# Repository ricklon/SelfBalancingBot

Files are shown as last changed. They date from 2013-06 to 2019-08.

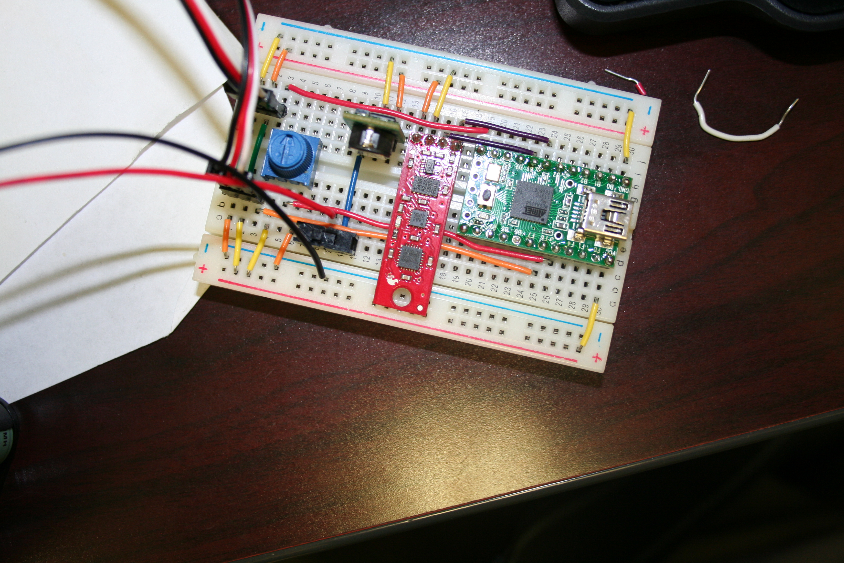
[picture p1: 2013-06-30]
docs/IMG_3596.JPG

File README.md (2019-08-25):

Self Balancing RoBot (SBR)
================
For more project information check out the [wiki](https://github.com/ricklon/SelfBalancingBot/wiki)

- [ ] Need to upgrade to faster motors
- [ ] Keep the servo style control
- [ ] May have to Create a a custom servo library
- [ ] Test with hobby gearnotor
- [ ] PID needs to coordinate 2 motors
- [ ] Would like to add support for mpu6500 and mpu9250
- [ ] Add multiple core support [Teensy 3.x, Fubarino Mini 2.0, esp32, esp8266]
- [ ] Motor controller l293d
- [ ] Evaluate power supply

This Self Balancing Robot project is for the Rutgers University  Governor School Course "How to Make a Self Balancing Robot" started by Aatish in 2012. He had the self balancing robot using the Sparkfun box. In addition Jason Doreweller, http://www.jddorweiler.appspot.com/electronics.html#robot,  created a Self Balancing Robot at Fubar Labs in 2012. Concepts from that robot where tested, and modeled developing this new robot.

This project has added:
* servo calibration sketches
* data gathering sketches and test for the accelermeter
* data gathering sketches and test for the gyro
* A servo movement library
* PID, Kalman fileter library

Arduino libraries used in the project:
* Servo
* ITG3200
* ADXL445
* Serial

BOM:
* Teensy 2.0
* 2 Parallax Continuous Servos
* 5v Switching voltage regulator
* Sparkfun 9 DOF freedom IMO

Note: Using the Teensy eliminated the Serial vs Servo timer problem.

Laser cut reference design for a body to mount the project.

Notes for Teensy 2.0
====
[I2C pin out]( http://www.pjrc.com/teensy/pinout2b.png)

[Teensy 2.0 pin mapping](http://www.pjrc.com/teensy/pinout.html)

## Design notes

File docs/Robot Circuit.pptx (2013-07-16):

## Robot Circuit

## Wiring

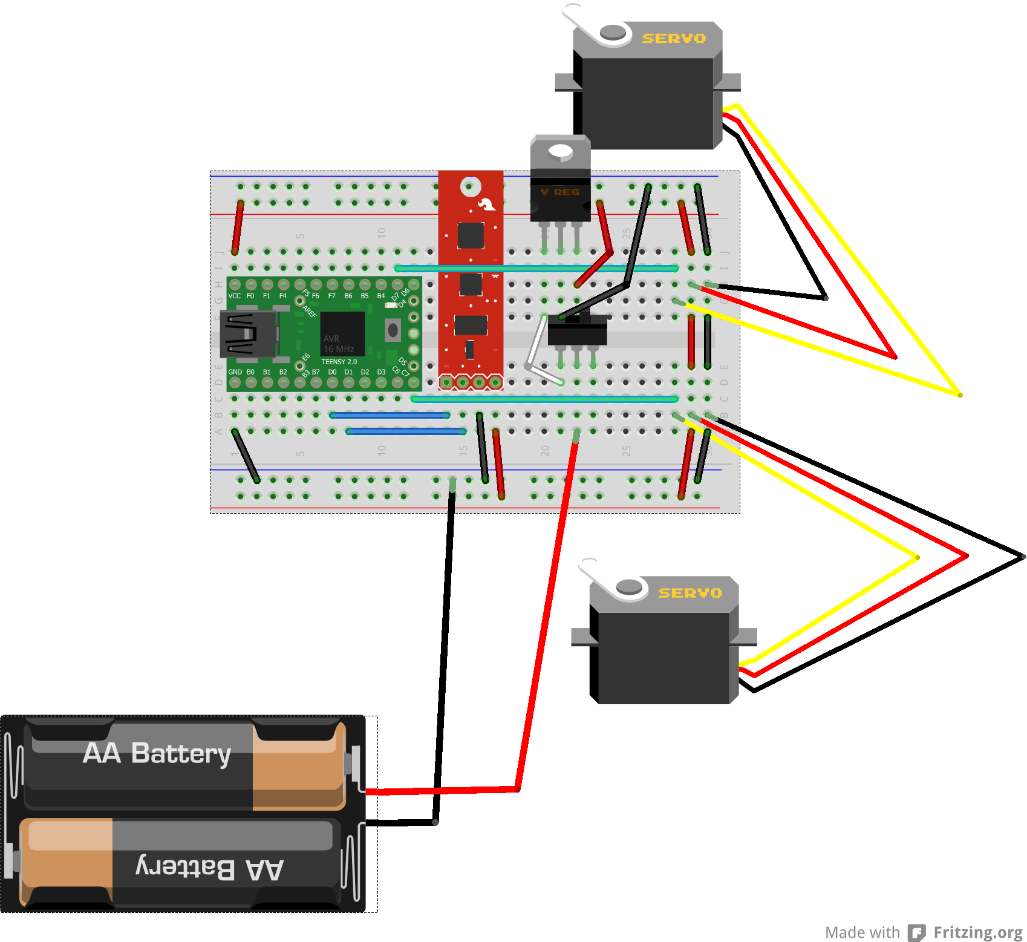
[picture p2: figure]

## Schematic

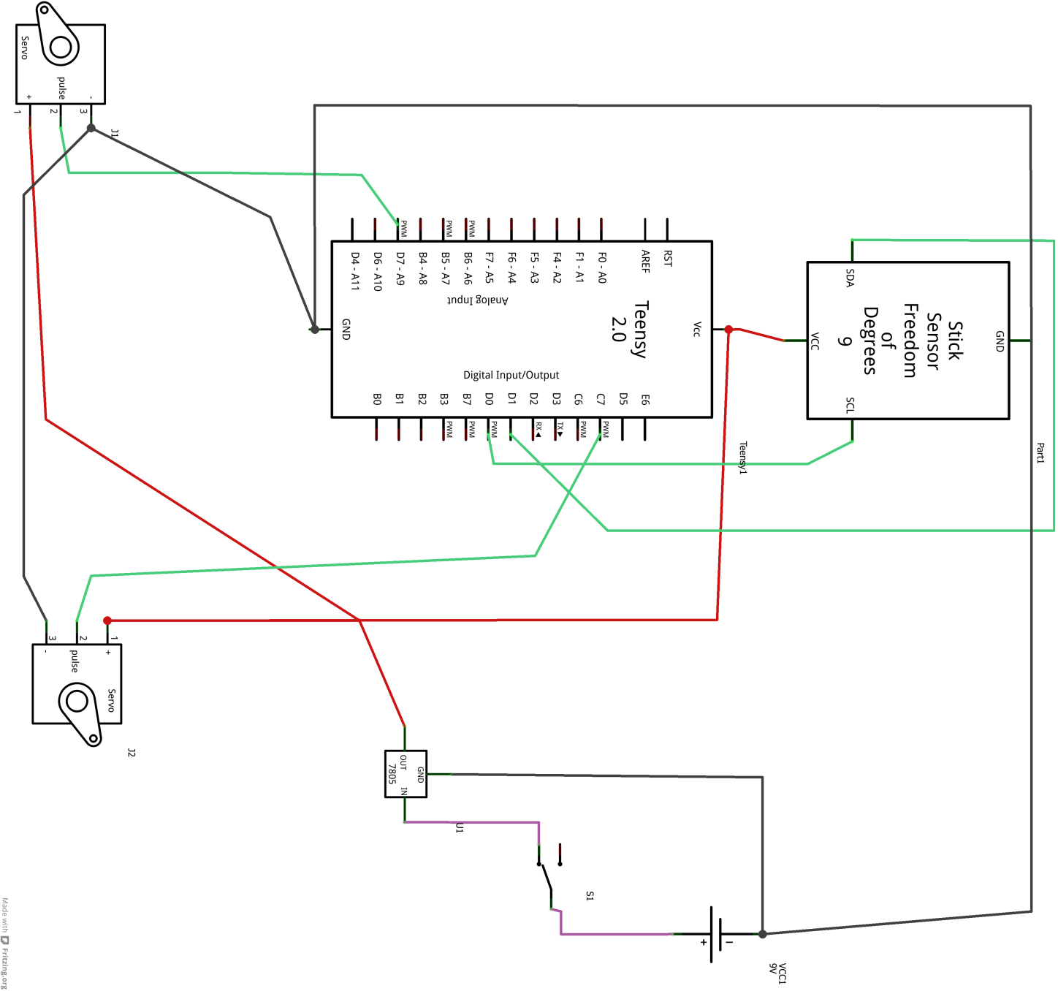
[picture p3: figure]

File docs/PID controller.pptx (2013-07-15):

## PID controller

## What’s a PID controller?

- A PID is defined by the following Equation
- Think of the Integral term as the “past”
- Think of the e(t) (proportional) term as “Now”
- Think of the Derivative term as the “Future”
- The constants reflect how important we think each of the other components are.

## In code: Setup

void setup()
{
…
for (int i = 0; i < REF_ANGLE_SAMPLES; i++){
getAccAngle();
getGyroValues();
maxGyro = absMax(gy,absMax(gx,gz));
maxAngle = absMax(theta,psi);
angle = compositeFilter( maxAngle, float(maxGyro), SAMPLE_RATE, angle);
refAngle += angle; delay(SAMPLE_RATE);
}
refAngle /= REF_ANGLE_SAMPLES;
…
}

## In code: Loop

void loop()
{
…
angle = compositeFilter( maxAngle, float(maxGyro), rate, angle);
float error = angle - refAngle;
integral = integral + error * rate;
derivative = (error - prevError) / rate;
spd = (KP * error) + (KI * integral) + (KD * derivative);
prevError = error;
…
}

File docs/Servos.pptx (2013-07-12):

## Servos

## Controlling Rotation

Continuous Servo | Standard Servo | Stepper | Direct Motor
Pros: PWM speed control | Pros: PWM angle control | Pros: Precise angle control and Continuous rotation | Pros: Fast
Cons: No fine angle control | Cons: Upper limit on Turning | Cons: SLOWEST | Cons: No precision speed control (ON or OFF)

- It is possible to directly connect a motor to the arduino. I DO NOT recommend doing this. http:// (http://www.instructables.com/id/Simple-2-way-motor-control-for-the-arduino/?ALLSTEPS)www.instructables.com (http://www.instructables.com/id/Simple-2-way-motor-control-for-the-arduino/?ALLSTEPS)/id/Simple-2-way-motor-control-for-the- (http://www.instructables.com/id/Simple-2-way-motor-control-for-the-arduino/?ALLSTEPS)arduino (http://www.instructables.com/id/Simple-2-way-motor-control-for-the-arduino/?ALLSTEPS)/? (http://www.instructables.com/id/Simple-2-way-motor-control-for-the-arduino/?ALLSTEPS)ALLSTEPS (http://www.instructables.com/id/Simple-2-way-motor-control-for-the-arduino/?ALLSTEPS)
- We’re taking the Continuous Servo as the best compromise.

## Servo Wiring

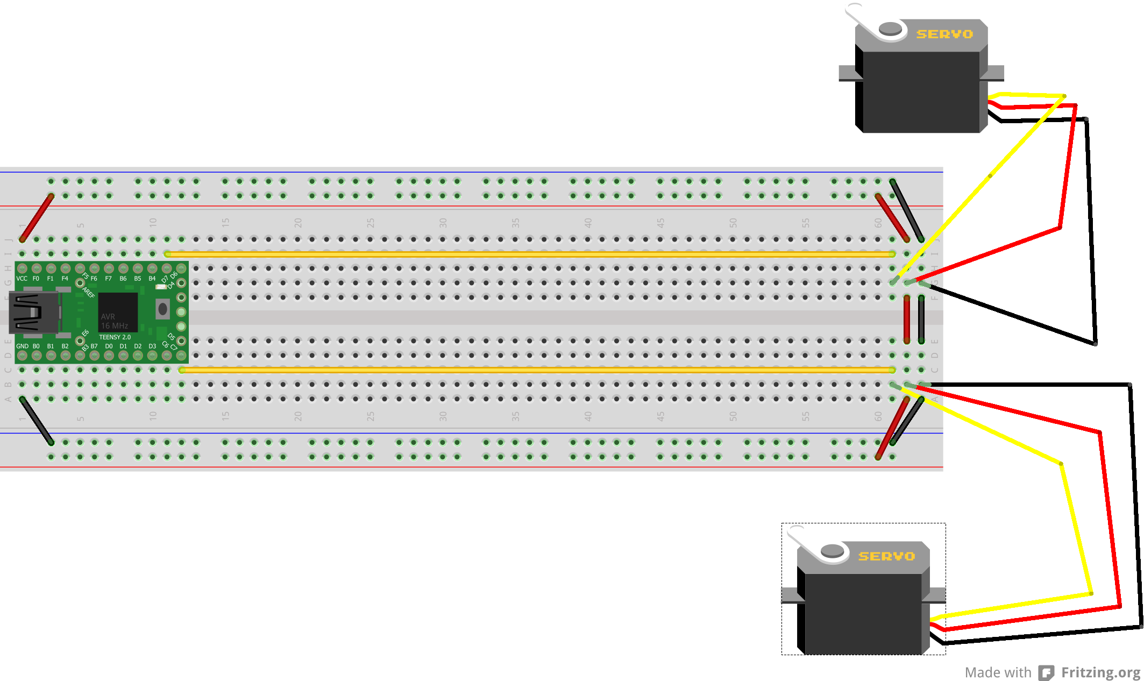
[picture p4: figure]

## Servo Circuit

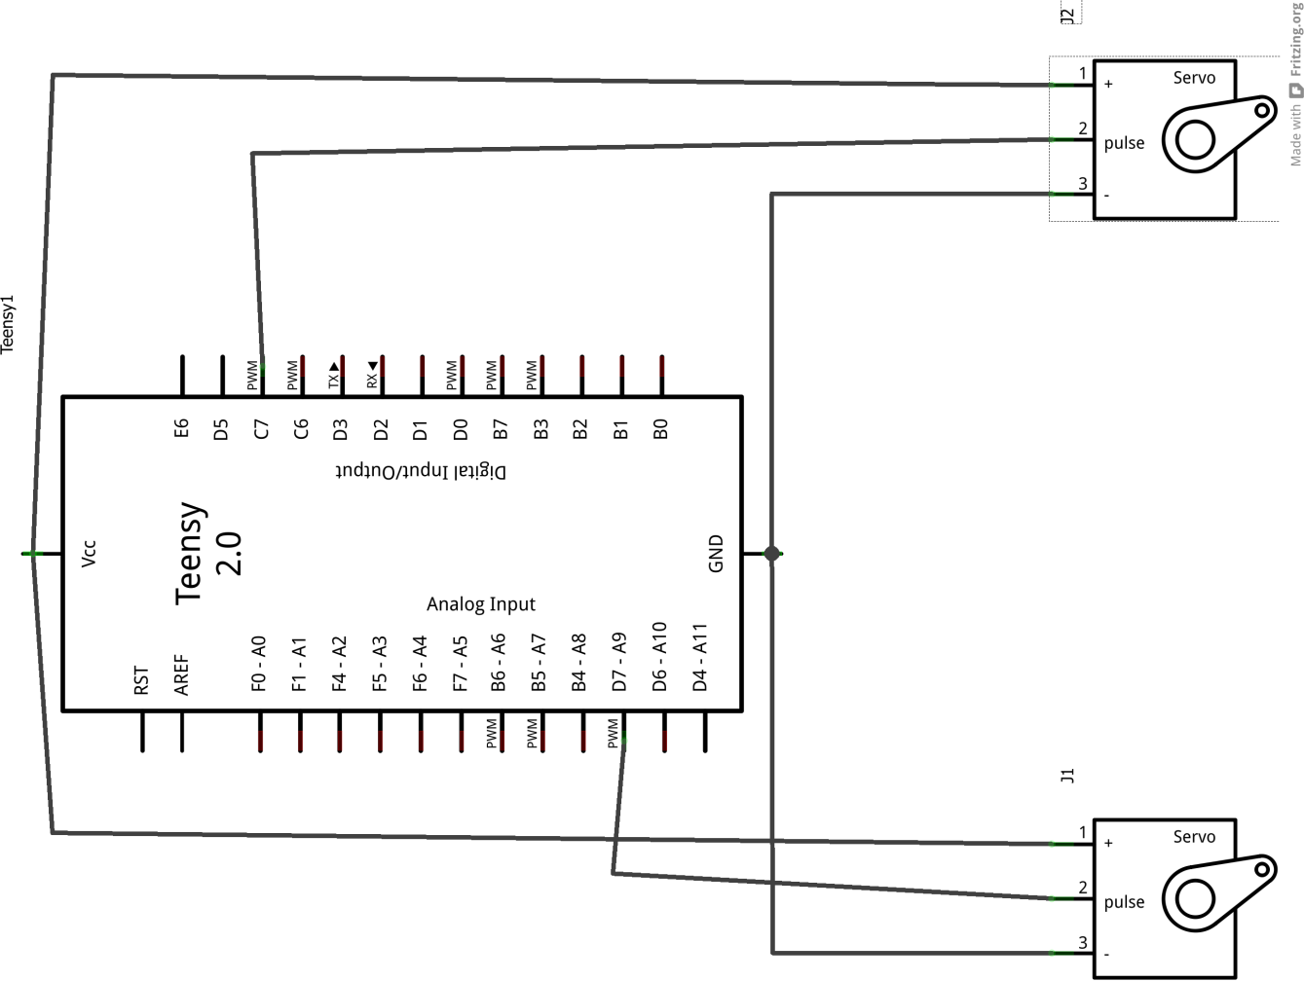
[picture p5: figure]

## PWM

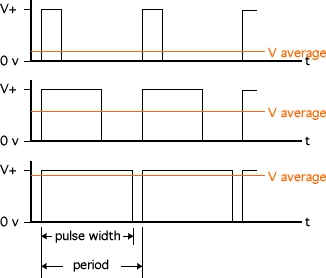
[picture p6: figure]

## Units

- Accelerometer function outputs angles in degrees
- Gyro outputs angle rates in degrees/sec
- Servo in controlled by Pulses in units of Microseconds?
- Servo max speed is in RPM? How do we convert?
- 1(Degrees)/(Seconds)=(Degrees)/(Seconds)∗(60 Seconds)/(Minute)∗(rotation)/(360 degrees)=1/6(rotation)/(minute)
- Need a conversion function from pulse widths to rotation speeds in (…)?

## Controlling the Servo

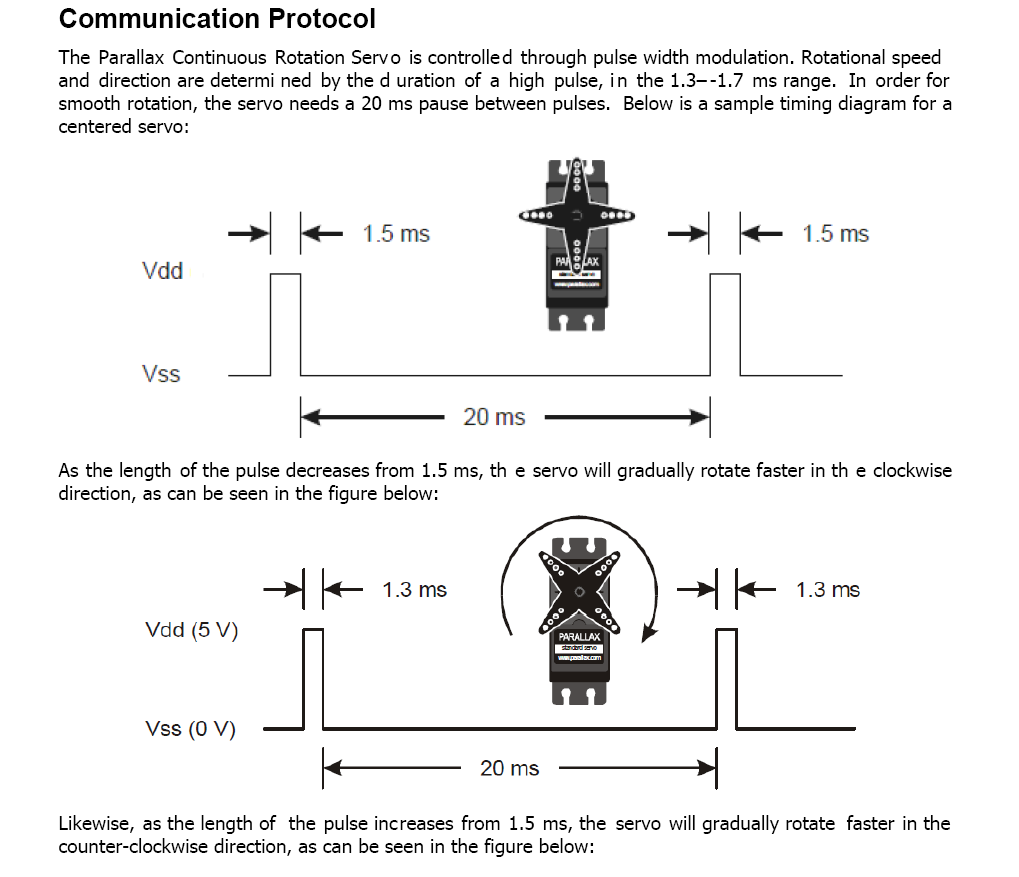
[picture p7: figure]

## Controlling the Servo cont.

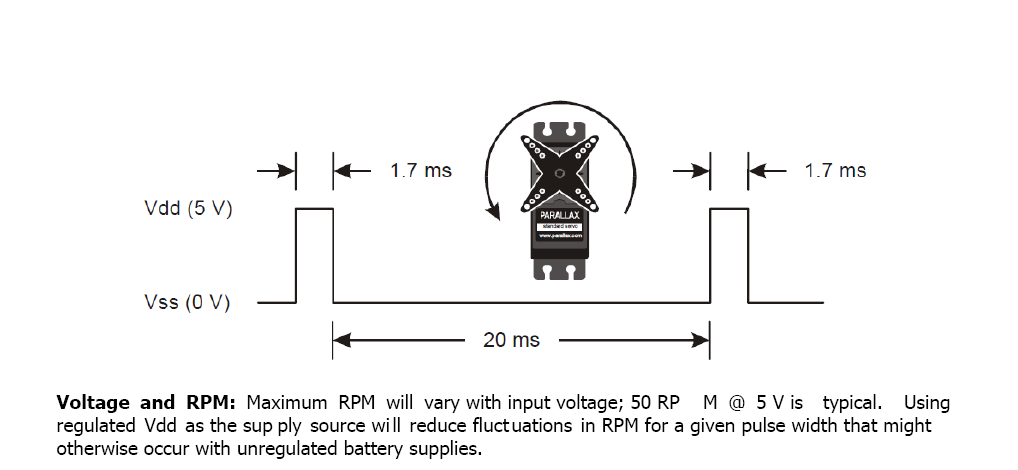
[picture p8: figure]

## Servo Setup Code

#include <Servo.h>

#define SERVO1_PIN 10

#define SERVO2_PIN 12

#define LED_PIN 11

#define SERVO_ZERO 1500

char buff[5];
int ii = 0;
Servo servo1;
Servo servo2;
int ledState = 0;
void setup() {
servo1.attach(SERVO1_PIN );
servo2.attach(SERVO2_PIN );
pinMode(LED_PIN, OUTPUT);
Serial.begin(9600);
}

## Servo Loop Code

void loop() {
ii=0;
while (Serial.available() > 0) {
buff[ii] = Serial.read();
Serial.print(buff[ii]);
if (buff[ii] == 0x0d ) {
pos = atoi(buff);
break;
}
ii++;
}

## Servo Loop Code cont.

ledState += 1; if ((ledState % 2) == 0){
digitalWrite(LED_PIN, HIGH); servo1.writeMicroseconds(pos);
rpos = map(pos, 1300, 1700, 1700, 1300);
servo2.writeMicroseconds(rpos);
}
else {
digitalWrite(LED_PIN, LOW);
servo1.writeMicroseconds(SERVO_ZERO); servo2.writeMicroseconds(SERVO_ZERO);
}

## Build a “calibration curve”

Find the pulse widths that made the servo rotate at (each servo is a little different, don’t blindly copy):
- 300 deg/sec
- 270 deg / sec
- 180 deg / sec
- 90 deg/ sec
- 45 deg / sec
- Negative counterparts.

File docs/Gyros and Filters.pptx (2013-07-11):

## Gyros and Filters

## Our old friends FREE IMU

- Use the ITG3200 library to setup the gyro
- Run startup calibration
- Get gyro data

## Setting up the gyro

#define SAMPLE_RATE 7.0

ITG3200 gyro = ITG3200();
void gyrobegin(){
gyro.reset();
gyro.init(ITG3200_ADDR_AD0_LOW);
DEBUG_PRINT("zeroCalibrating...");
gyro.zeroCalibrate(2500,2);
DEBUG_PRINTLN("done.");
delay(100);
}
void setup(){
pinMode(LED_PIN, OUTPUT);
digitalWrite(LED_PIN, HIGH);
DEBUG_BEGIN(115200);
Wire.begin();
gyrobegin();
digitalWrite(LED_PIN, LOW);
lastMilli = millis();
}

## Getting some readings

void getGyroValues(){
float xyz[3];
gyro.readGyro(xyz);
gx = xyz[0];
gy = xyz[1];
gz = xyz[2];
}
void loop() {
curMilli = millis();
if ((curMilli - lastMilli) > SAMPLE_RATE){
getGyroValues();
int gyroMax = absMax(gy,absMax(gx,gz));
lastMilli = curMilli;
DEBUG_PRINT(curMilli);
DEBUG_PRINT(" , ");
DEBUG_PRINT(gyroMax);
}
else if((curMilli - lastMilli) < 0){
lastMilli = curMilli;
}
}

## Filtering – The low pass

- At low frequencies, there is plenty of time for the capacitor to charge up to practically the same voltage as the input voltage.
- At high frequencies, the capacitor only has time to charge up a small amount before the input switches direction.
- The output goes up and down only a small fraction of the amount the input goes up and down.
- This effectively limits how “fast” we can change something

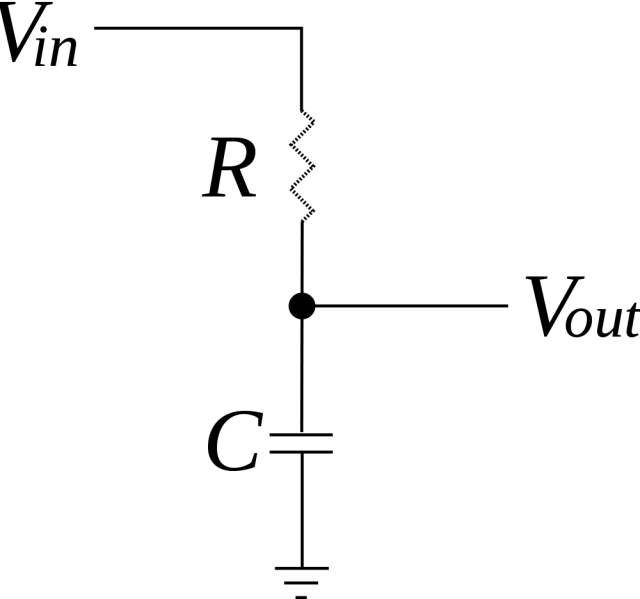
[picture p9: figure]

## The effect

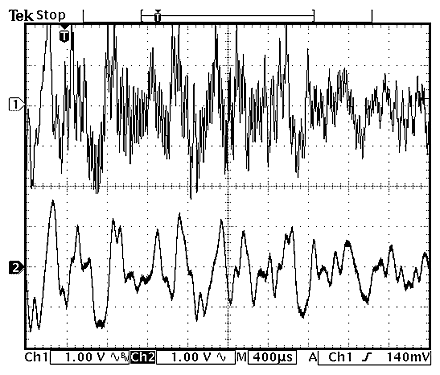
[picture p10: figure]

## Coposite filtering

- The high pass does the exact opposite of the low pass
- The gyro drifts but is relatively noise free
- The accelerometer oscillates wildly around the mean value
High pass expression : output y_i is related to input x_i (0<α<1)
Low Pass Expression
The solution: Low pass the Accelerometer and High Pass the Gyro

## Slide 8

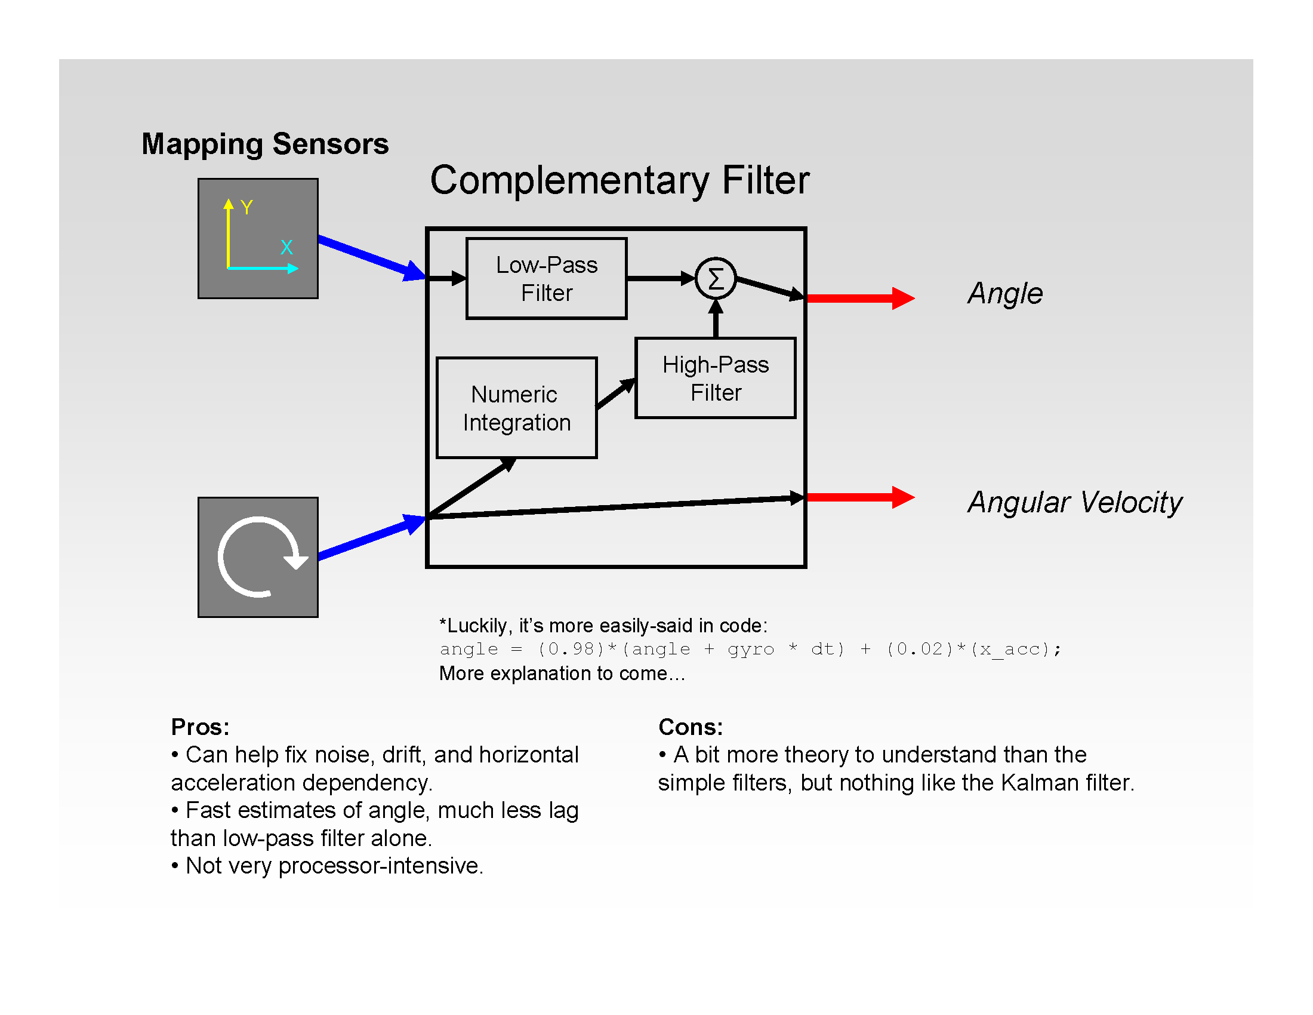
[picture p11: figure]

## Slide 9

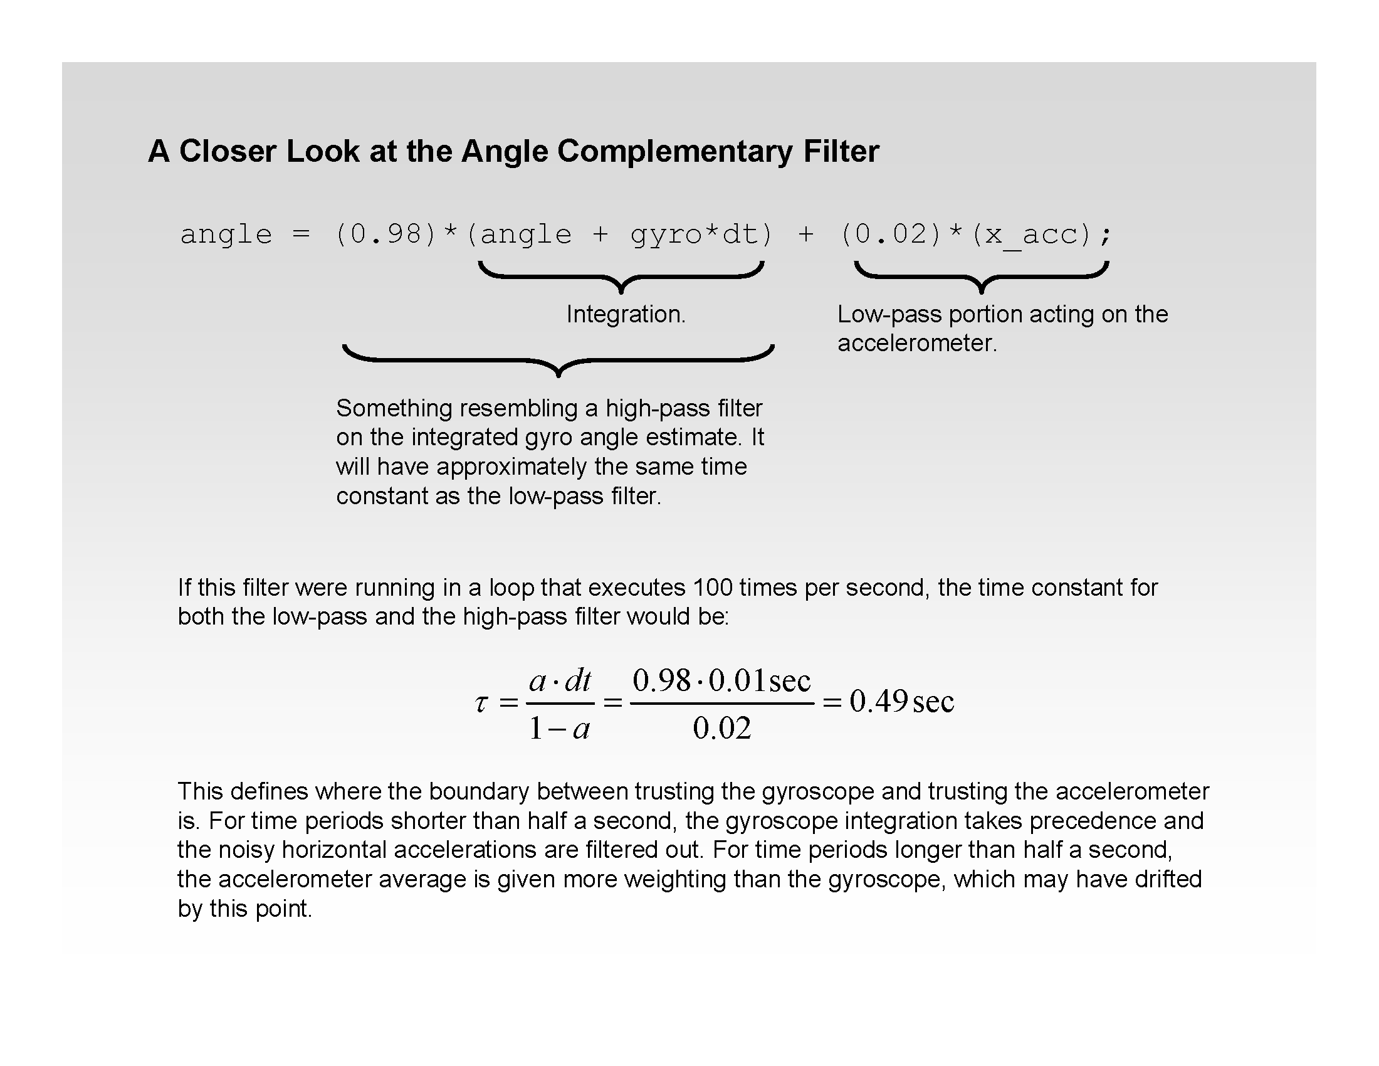
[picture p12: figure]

## Composite Filtering Code

alpha = TIME_CONSTANT / (TIME_CONSTANT + SAMPLE_RATE); // calculate the scaling coefficent
float compositeFilter(float acc, float gyro, float rate, float angle){
return alpha * (angle + (gyro * rate)) + (1 - alpha) * acc; // the actual filter
}
use this in the merger of the previous code.

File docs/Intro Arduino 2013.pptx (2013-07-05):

## Introduction to Programming with the Arduino 2013

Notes: 1. Add photos of the circuits
2. Show more clearly how energy flows through breadboard
3. Explain connectivity and wires
4. Show the wiring of the breadboards
5. Parts, and wires need to share the same row
6. Explain the LED before wiring, do an LED to battery. Maybe, burn it out to show the problem of no resistor.
7. Explanation of polarity in regards to troubleshooting and debugging.
8. Show in diagrams the part in holes more clearly.

## What Arduino are we using today?

Teensy 2.0 Arduino variation

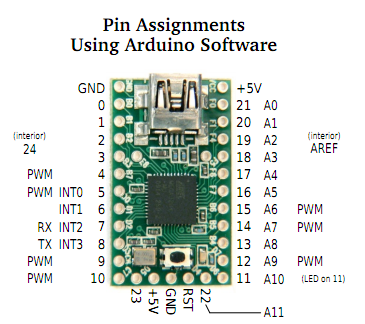
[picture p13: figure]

## Breadboards

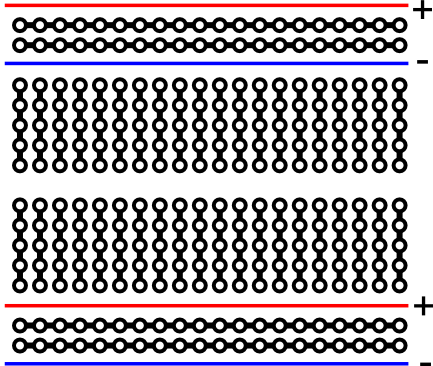
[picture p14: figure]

## Exercise 1: Blink the LED

Blink 'Hello World' of microcontrollers.
It demonstrates digital output.
It also tells you that your device is working.
The Teensy has an on board LED on PIN 11.
We will configure the Arduino to blink an external LED on pin 11. So both blink at the same time.

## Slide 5

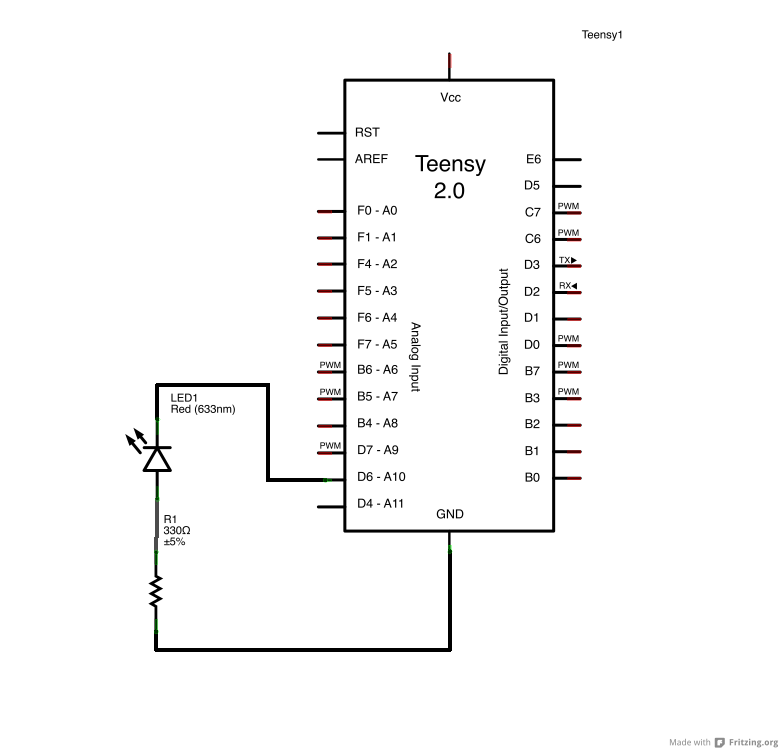
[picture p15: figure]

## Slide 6

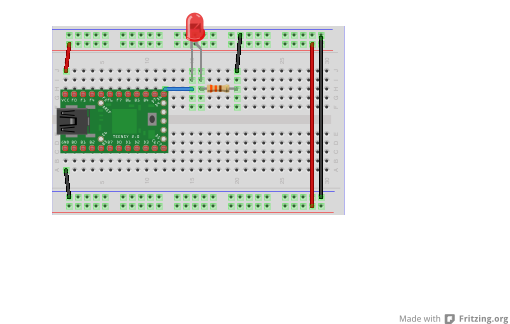
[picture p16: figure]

LED positive (long) leg connected to pin 11

## Blink an LED

void setup()
{ //runs once

}

void loop()
{ //executed repeatedly

}

## Blink an LED

int ledPin = 11; //led on pin 11
//defined in one place for our convenience
void setup()
{

}

void loop()
{

}

## Blink an LED

int ledPin = 11; //led on pin 11

void setup()
{ pinMode(ledPin, OUTPUT);
}

void loop()
{

}

## Blink an LED

int ledPin = 11; //led on pin 11

void setup()
{
pinMode(ledPin, OUTPUT);
}

void loop()
{ digitalWrite(ledPin, HIGH);
}

## Blink an LED

int ledPin = 11; //led on pin 11

void setup()
{
pinMode(ledPin, OUTPUT);
}

void loop()
{
digitalWrite(ledPin, HIGH); digitalWrite(ledPin, LOW);
}

## Blink an LED

int ledPin = 11; //led on pin 11

void setup()
{
pinMode(ledPin, OUTPUT);
}

void loop()
{
digitalWrite(ledPin, HIGH); delay(1000);
digitalWrite(ledPin, LOW); delay(1000);
}

Declaration of a function with VOID return type

Single line comment

Declaration of an integer

Calling a predefined function

Function arguments (constants)

Reserved words

## Blink an LED

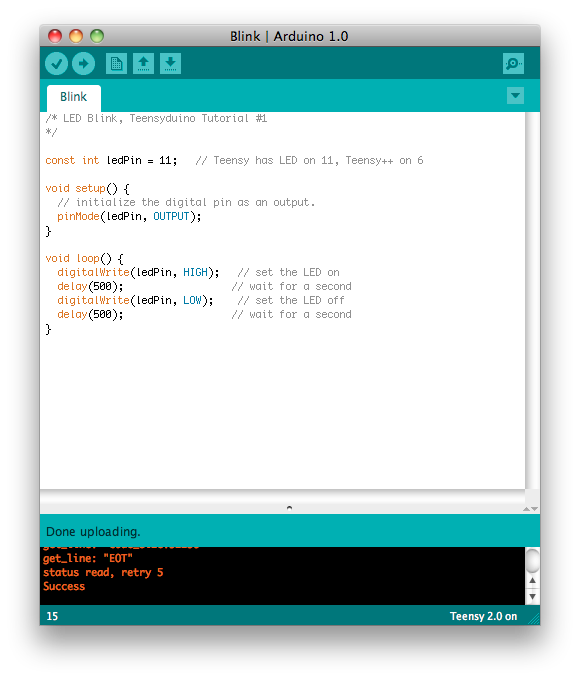
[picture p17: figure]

## Blink an LED

Verify = Compile and debug

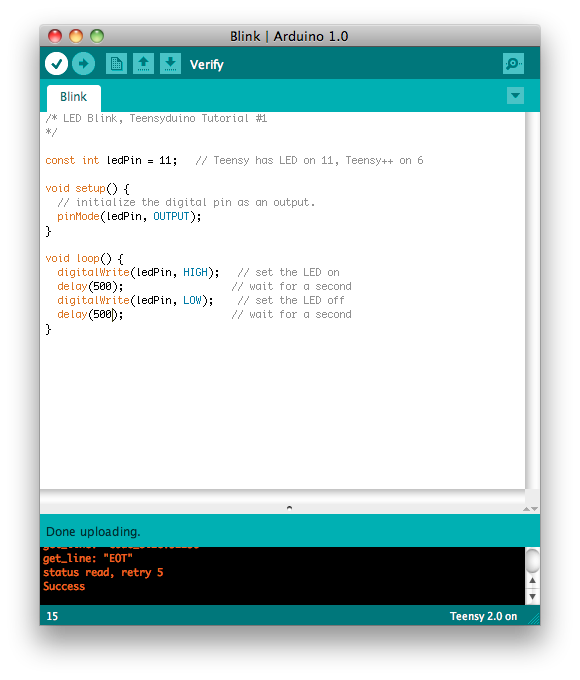
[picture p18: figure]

## Blink an LED

Upload = Compile and Upload to the board

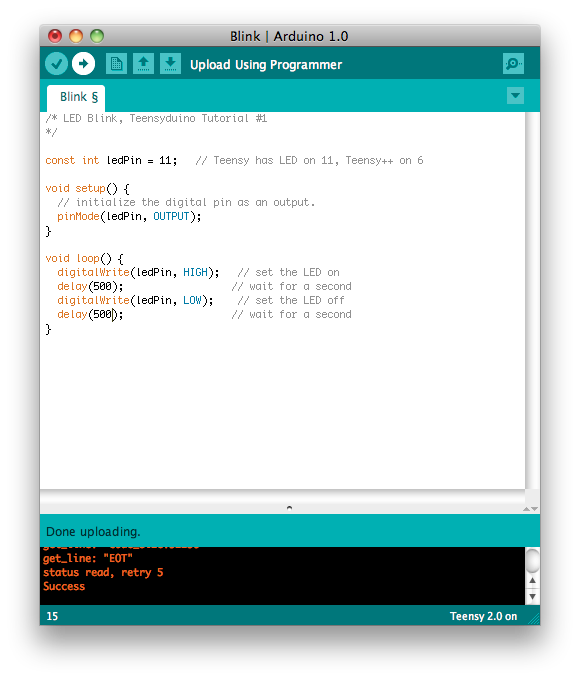
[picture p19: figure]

## Other uses for digital output

- Switching other devices on/off
  - Relays - Can open/close a switch in a separate circuit for controlling high-power loads and avoiding electrical noise
  - Transistors - Can be used to amplify a signal to much higher power than the microcontroller alone
- Communication
  - Software Serial

## Analog out with PWM

PWM - Stands for Pulse Width Modulation
So far we know how to turn an output OFF or ON (LOW and HIGH)
What if we want to change the speed of a motor, or the intensity of a light?
PWM output is a signal where the output switches very rapidly between fully on and fully off. For a lower value, the output is on a smaller percentage of the time, for a higher value, the output is on for a larger percentage of the time.

## PWM


## Exercise 3- Fade an LED on/off

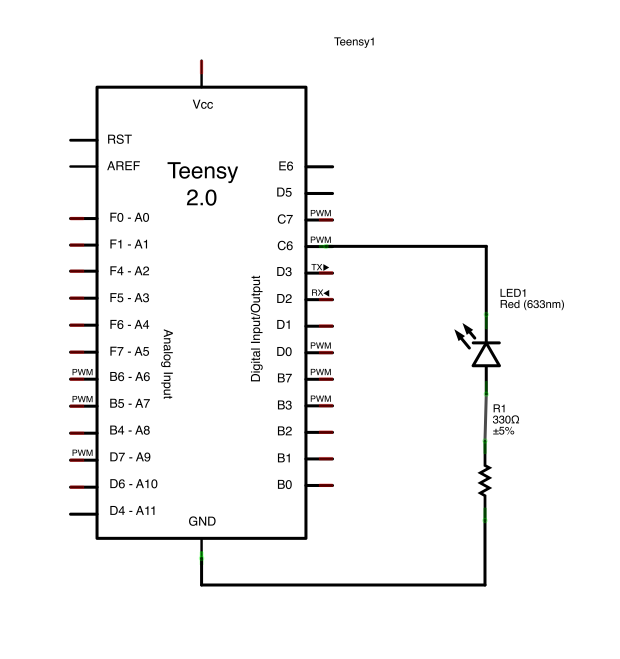
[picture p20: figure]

## Exercise 3- Fade an LED on/off

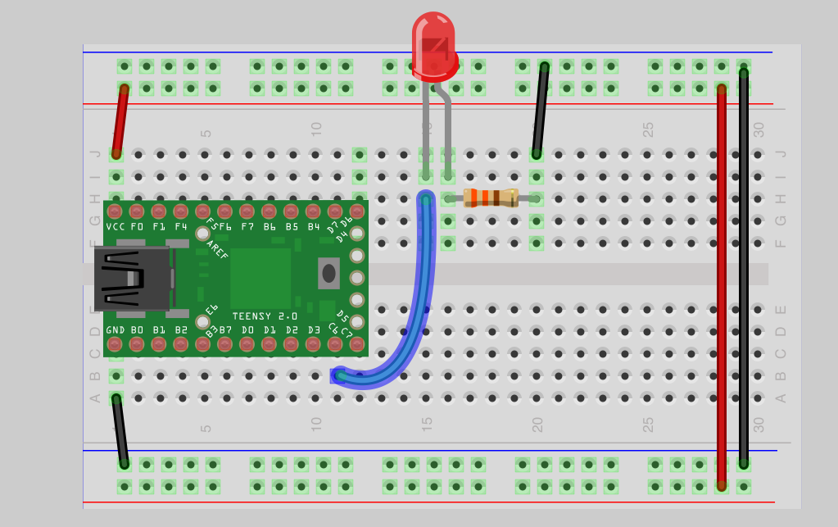
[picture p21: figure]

## Two ways to fade an LED

First way is to use void loop()
Increment and decrement the values every time through the loop. Same setup will be used in both examples:
/*==========================================================*/
const int ledPin = 9;
int brightness = 0; // how bright the LED is
int fadeAmount = 5; // how many points to fade the LED by
void setup() {
// declare pin 9 to be an output:
pinMode(ledPin, OUTPUT);
}

## Fade inside loop()

const int ledPin = 9;
int brightness = 0; // how bright the LED is
int fadeAmount = 5; // how many points to fade the LED by
void setup() {
// declare pin 9 to be an output:
pinMode(ledPin, OUTPUT);
}
void loop() {
// set the brightness of pin 9:
analogWrite(ledPin, brightness);
// change the brightness for next time through the loop:
brightness = brightness + fadeAmount;
// reverse the direction of the fading at the ends of the fade:
if (brightness == 0 || brightness == 255) {
fadeAmount = -fadeAmount ;
}
// wait for 30 milliseconds to see the dimming effect
delay(30);
}

## Fade an LED - using a for loop

- Use the same setup code as before
- Same circuit
- You can use save as and delete the code in loop and replace with the new code

## The for loop

for(int t=0; t<=100 ; t+=1)
{
//Do something 100 times
}

## Fade an LED - the Code

void loop()
{
for( )
{
// What goes in the for loop?
// sets the value (range from 0 to 255. 8 bit resolution):
analogWrite(ledPin, fadeValue);
}
}

## Fade an LED - the Code

void loop()
{
for(int fadeValue = 0 ; fadeValue <= 255; fadeValue +=5)
{
// sets the value (range from 0 to 255):
analogWrite(ledPin, fadeValue);
}
}

## Fade an LED - the Code

void loop()
{
for(int fadeValue = 0 ; fadeValue <= 255; fadeValue +=5)
{
// sets the value (range from 0 to 255):
analogWrite(ledPin, fadeValue);
// wait for 30 milliseconds to see the dimming effect
delay(30);
}
}

## Fade an LED - the Code

void loop()
{
for(int fadeValue = 0 ; fadeValue <= 255; fadeValue +=5)
{
// sets the value (range from 0 to 255):
analogWrite(ledPin, fadeValue);
// wait for 30 milliseconds to see the dimming effect
delay(30);
}
// duplicate in reverse
for(int fadeValue = 255 ; fadeValue >= 0; fadeValue -=5)
{
// sets the value (range from 0 to 255):
analogWrite(ledPin, fadeValue);
// wait for 30 milliseconds to see the dimming effect
delay(30);
}
}

## 1 circuit -- 1,000 behaviors

With one simple circuit, you can write many behaviors just by changing the software, without having to alter the circuit or add additional components.

## Digital vs Analog

What things are digital?
What things are analog?
What things appear to be digital or analog?
How can we communicate exact values?
How about approximate values?
What about minimum values?
What about maximum values?

## Serial Output

Serial.begin(9600);
Starts the serial connection - call once at start of sketch

Serial.println(someValue);
Sends someValue across the serial connection with a newline character.
var = Serial.read();
Returns incoming serial data, stores it in var

## Exercise: Another Hello World

void setup()
{
Serial.begin(9600);
}

void loop()
{
Serial.println("Hello World");
delay(1000);
}

## Analog Input

val = analogRead(analogPin);
Reads voltage on analog input pins and translates to a numerical value.
Value is based on percentage of reference voltage (in this case 5v)
The reading has a 10 bit resolution (returns a value in the range 0-1023)

## Analog Read code

int sensorPin = A0;
int sensorVal = 0;
void setup()
{
Serial.begin(9600); // setup serial
pinMode(sensorPin, INPUT);
}

void loop()
{
sensorVal = analogRead(sensorPin); // read the input pin
Serial.println(sensorVal); // debug value
}

## Blink with out delay:

Let’s Rewrite blink with out delay.
What will we need?
- A Fixed time stamp (What units?)
- A reading of the current clock value
- Something to track the current state
- Some conditional expression that checks if the amount of time passed is more than the length of time we want the led to stay on/off
- A refrence:
- http:// (http://arduino.cc/en/Tutorial/BlinkWithoutDelay)arduino.cc (http://arduino.cc/en/Tutorial/BlinkWithoutDelay)/en/Tutorial/ (http://arduino.cc/en/Tutorial/BlinkWithoutDelay)BlinkWithoutDelay (http://arduino.cc/en/Tutorial/BlinkWithoutDelay)

## Blink with out delay

- const int ledPin = 11; int ledState = LOW; //LOW is a reserved word
- long previousMillis = 0; // Which one is this? long interval = 1000;
- void setup() { pinMode(ledPin, OUTPUT); //setup }  void loop() { unsigned long currentMillis = millis();  if(currentMillis - previousMillis > interval) { previousMillis = currentMillis; // why is this here? if (ledState == LOW) ledState = HIGH; else ledState = LOW; digitalWrite(ledPin, ledState); } }

## Exercise 5 - LED dimmer control

The circuit

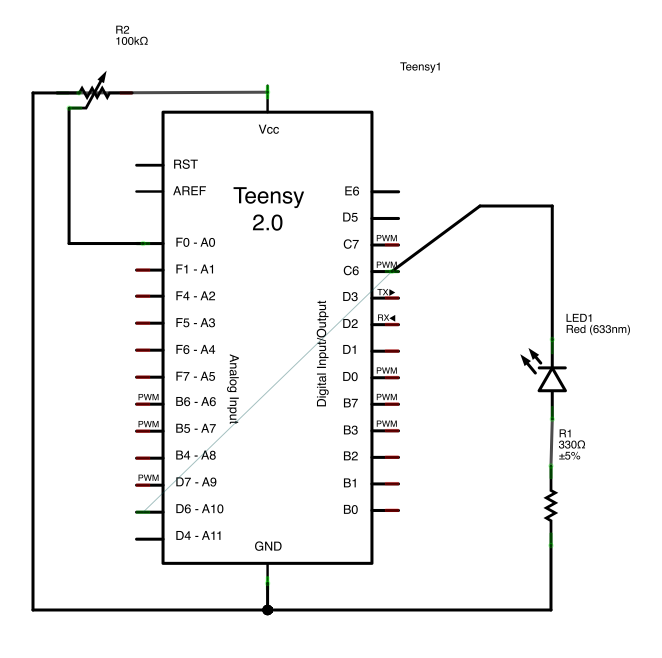
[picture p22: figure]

## Starting Circuit

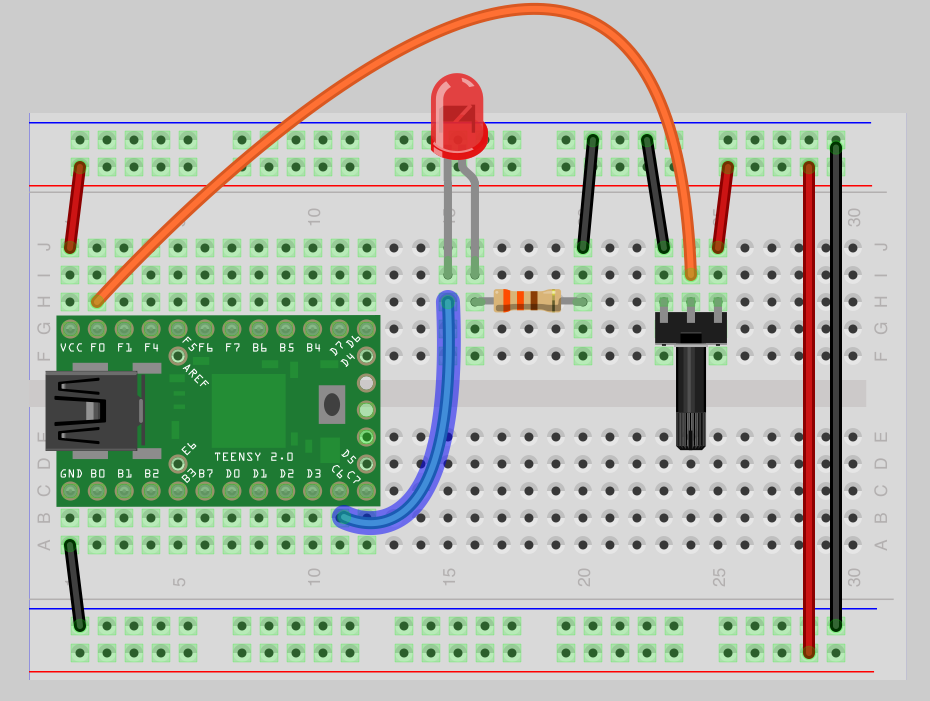
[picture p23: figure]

## Dimmer Control code

int sensorPin = A0;
int ledPin = 9;
int sensorVal = 0;
void setup()
{
Serial.begin(9600); // setup serial
pinMode(sensorPin, INPUT);
pinMode(ledPin, OUTPUT);
}
void loop()
{
sensorVal = analogRead(sensorPin); // read the input pin
Serial.println(sensorVal); // debug value
analogWrite(ledPin, sensorVal/4);}

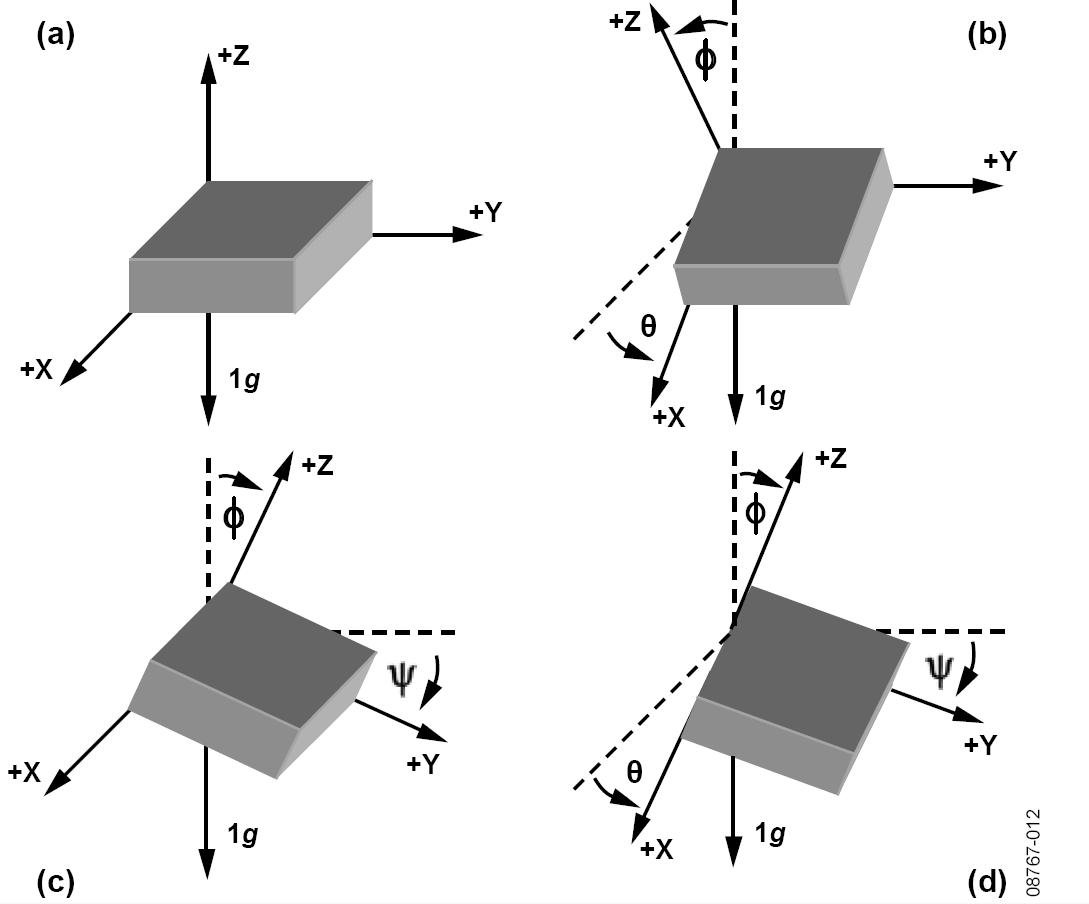
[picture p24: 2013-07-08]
docs/IMU_Angles.png

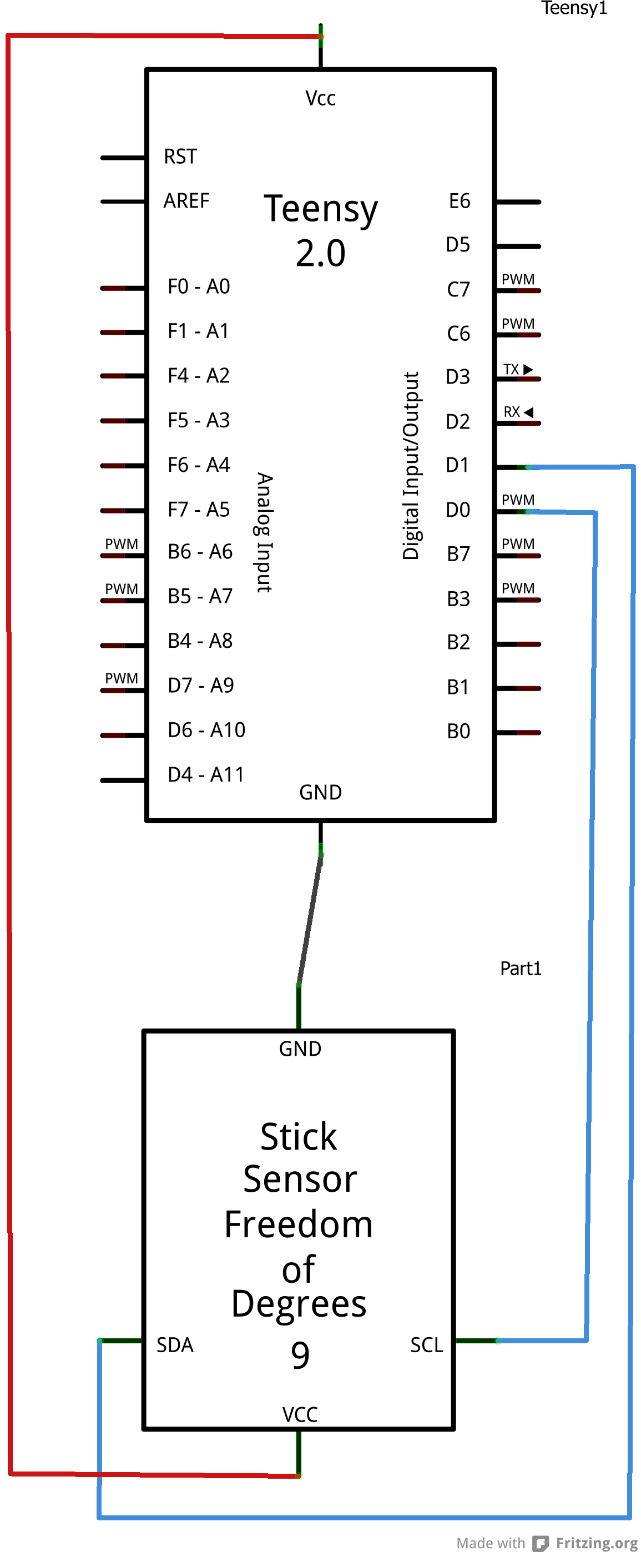
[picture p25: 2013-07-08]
docs/Teensy_IMU_schem.png

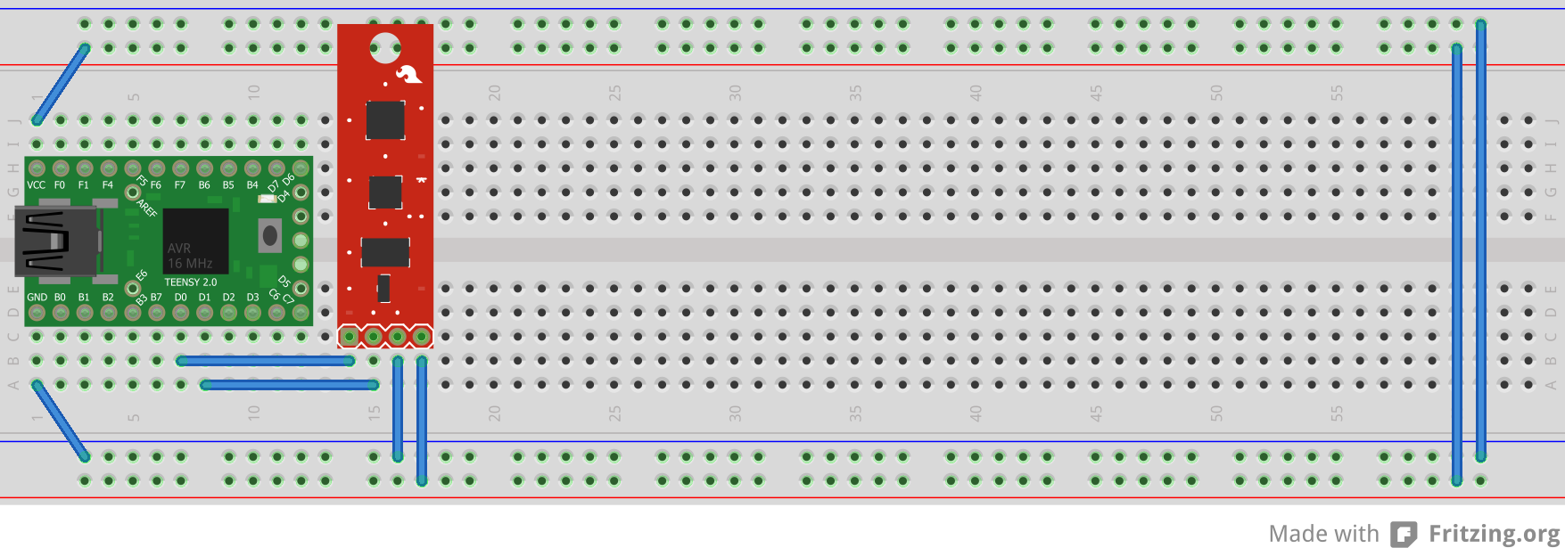
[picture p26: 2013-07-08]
docs/Teensy_IMU_bb.png

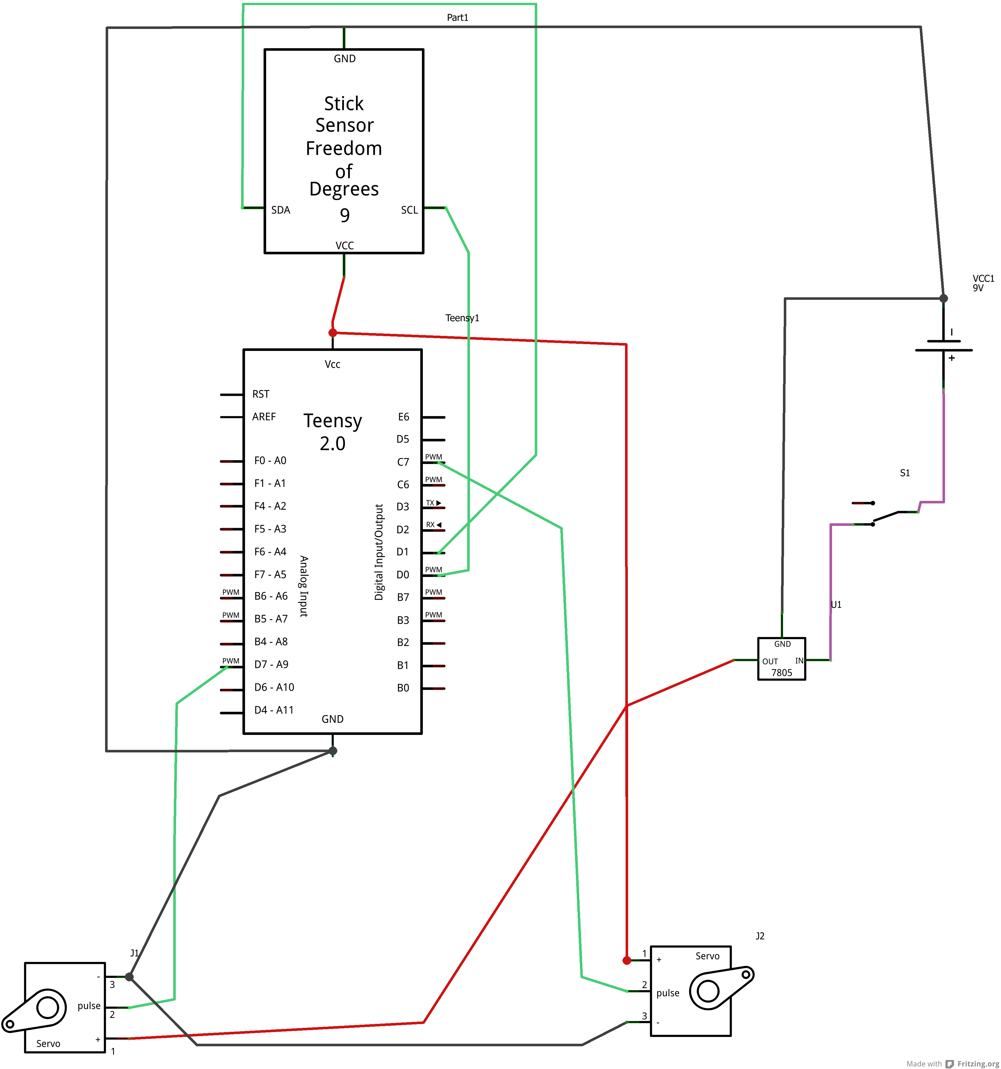
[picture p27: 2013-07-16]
docs/robut_schem.png

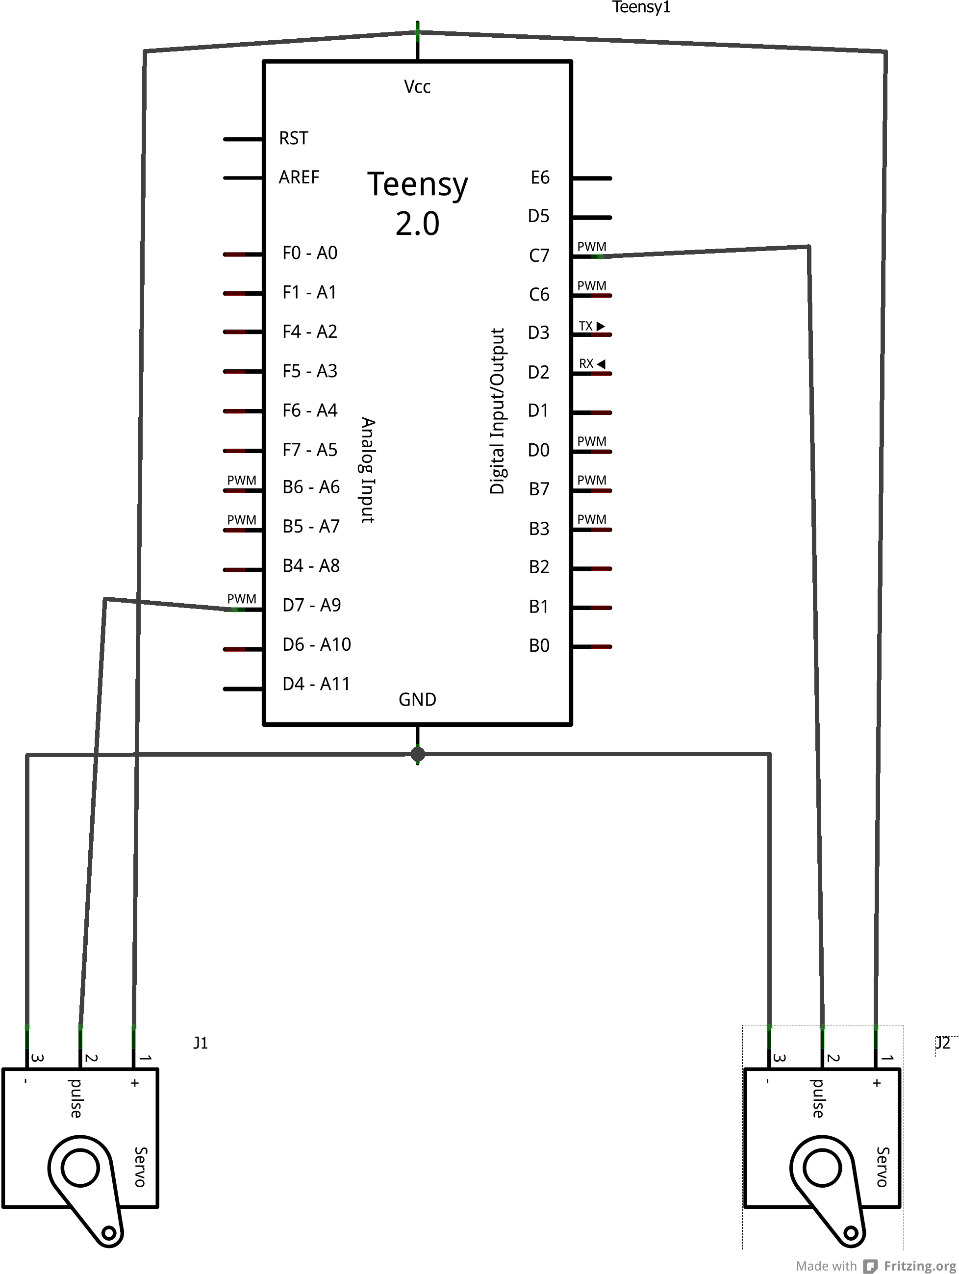
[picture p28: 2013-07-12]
docs/Servo_schm.png

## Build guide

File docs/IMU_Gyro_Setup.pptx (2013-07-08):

## IMU and Servo Setup

## Wiring the IMU

- The IMU Pins
  - VCC (+5 Volts) -> VCC
  - GND(Common) -> GND
  - SDA -> D1
  - SCL -> D0

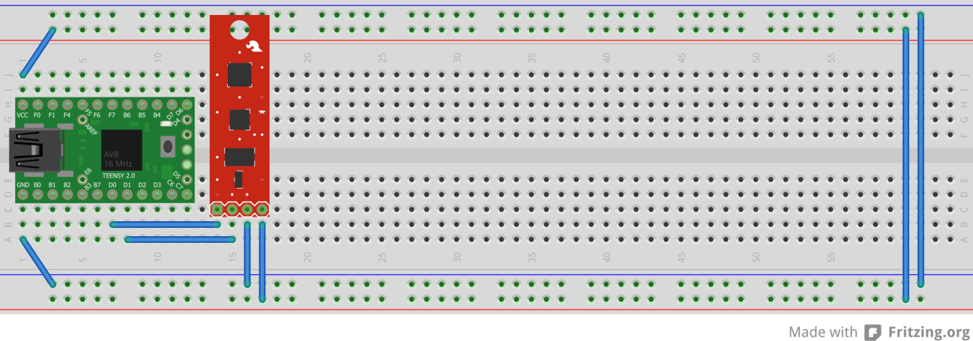
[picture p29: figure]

## Accelerometer: What are we reading?

- Acceleration due to gravity
- We are intrested in:
  - Theta
  - Psi


## Small Angle Approximation

- Θ=tan^(−1) ((A_x)/(√(A^2 _y +A^2 _z)))≈(A_x)/(√(A^2 _y +A^2 _z))
- Ψ=tan^(−1) ((A_y)/(√(A^2 _x +A^2 _z)))≈(A_y)/(√(A^2 _x +A^2 _z))
- Small Angle Approximation good to ±30°

## Reading the Accelerometer

- Use the FREE IMU library to get the raw Acceleration measurements out of the Accelerometer
- Compute Theta and Psi

## Setup

void accBegin(){
Accel.init(ADXL345_ADDR_ALT_LOW); Accel.set_bw(ADXL345_BW_12);
}
void setup(){
accBegin();
Serial.begin(115200);
}

## Angle Calculation

void getAccAngle(){
float acc_data[3];
Accel.get_Gxyz(acc_data);
theta = (acc_data[0]/sqrt(acc_data[1]*acc_data[1] + acc_data[2]*acc_data[2]))*180/PI;
psi = (acc_data[1]/sqrt(acc_data[0]*acc_data[0] + acc_data[2]*acc_data[2]))*180/PI;
}
void loop() {
getAccAngle();
Serial.print(millis());
Serial.print(" , ");
Serial.print(theta);
Serial.print(" , ");
Serial.println(psi);
}

## Sample Data

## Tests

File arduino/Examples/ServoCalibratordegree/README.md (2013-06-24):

Servo Calibration
====

Sketch: [Servo Calibration to Degrees](https://github.com/ricklon/SelfBalancingBot/tree/master/arduino/ServoCalibratordegree)

This sketech can be used for two purposes, to Zero the Servos, and to map out the calibration curve (pulse width in Mircoseconds Vs. Observed rotatoinal rate).
 
It was built for use with Parallax Continuous Rotation Servo (#900-00008). The stated max rotation rate is 50 RPM (300 Deg/Sec).  The stated limits on the pulse width are 1300 micro seconds to 1700 micro seconds. 1300 microseconds corresponds to -50 RPM rotation, and 1700 should be +50.  These nomial values are not correct, this code can be used to map out the  pulse with that corresponds to the effective rate by observing some specified values of the rotatio.  
 
This code can take in a value for the pulse witdh  via the serial interface and will run the servo at that rate for 2 seconds. During the "Run" time the led on the teensy will be lit. It will then set the pulse with to the nominal zero value (1500 micro seconds) for 2 seconds. During the "stop" time the led will be off.
 
To zero: Run the sketch and send it an edge value (e.g 1300) via serial so that it's at max rotation speed. Adjust the screws so that when the led is off, the servos are not moving.
 
To find the calibration:  Send a pulse width that is between 1300 and 1500 (e.g 1450).  Mark the servo so that you can observe a full rotation. Adjust this value and observe the servo until you find a value where the servo makes a single complete revolution (I put up a refrence pointing device like a finger or screwdriver to see when the rotation is complete).  At this value the servo is moving at 360 degrees per 2 seconds  (180 deg/sec = 30 RPM).  Repeat for additional angles (180, 90, etc…)  to get the full curve.

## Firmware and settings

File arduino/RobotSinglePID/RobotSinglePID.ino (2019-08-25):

/*
The actual robot code
 */

#include <Wire.h>
//#include <math.h>
#include <ITG3200.h>
#include <Servo.h>
#include "ADXL345.h"

//setup stuff
#define DEBUG
#define LED_PIN 11

//Servo stuff
#define SERVO1_PIN 10
#define SERVO2_PIN 12
#define SPD_WRITE_WAIT 5 // Duration limit on Chaning the Speed in milli
#define SERVO_CENTER 1500 // The center value of the servo (where it should be still)

//Cfilter stuff
#define TIME_CONSTANT 250.0 // time constant in milli
#define SAMPLE_RATE   7.0 // Assumed Sampled rate in milli

//PID stuff
#define KP 15
#define KI 0.0
#define KD 0.0
#define INTEGRAL_LIMIT 11.5
#define REF_ANGLE_SAMPLES 1000 // Number of samples to calcualte the ref angle

//Debug stuff
#ifdef DEBUG
#define DEBUG_BEGIN(x)   Serial.begin(x); // Fastest Transfer rate?
#define DEBUG_PRINT(x)    Serial.print (x)
#define DEBUG_PRINTLN(x)  Serial.println (x)
#else
#define DEBUG_BEGIN(x)
#define DEBUG_PRINT(x)
#define DEBUG_PRINTLN(x) 
#endif

// Library types
Servo servo1 , servo2;
ITG3200 gyro = ITG3200();
ADXL345 Accel;


unsigned long curMilli = 0;
unsigned long lastMilli = 0;
unsigned long spdMilli = 0;

int resPos = 0;
int gx = 0;
int gy = 0;
int gz = 0;
int pos = 0;
int rpos = 0;
int maxGyro = 0;

float spd = 0.0;
float angle = 0.0;
float refAngle = 0.0;
float prevError = 0.0;
float integral = 0.0;
float theta = 0.0;
float psi = 0.0;
float alpha = 0.0;
float derivative = 0.0;
float rate = 0.0;
float maxAngle = 0.0;

/*
-------------- Servo mangment functions --------------------------
 */

void SBRServoBegin(int pin1, int pin2, unsigned long curMilli)
{

  servo1.attach(pin1);  // attaches the servo 
  servo2.attach(pin2);  
  spdMilli = curMilli;
}

/*
-------------- Speed Setting function --------------------------
 */

int setSPD(float spd, unsigned long curMilli) 
{
  /*
  This function will set the speed of the servos. It takes spd argument in deg/sec (-300, 300), and uses an aproximated
   calibration curve to set the pulse width. Sine the servos require some time to adjust the speed there is 
   lag check that will immedately return if there wasn't enough time between calls to the function
   */

  unsigned long dur = curMilli - spdMilli;

  if ( dur < SPD_WRITE_WAIT){ // return -1 if we haven't passed through the time limit, HOW do we prevent this from overflowing?
    return -1;
  } 
  spdMilli = curMilli; // Setting speed, so update clock

  /*
 This is an exact calibration curve, was built by hand using the servocalibrate degree sketch
   */
  if ( spd >= 300.0){
    pos = 1700;
    digitalWrite(LED_PIN, LOW);
  }
  else if ( 180.0 <= spd && spd < 300.0){
    pos =  1559;
    digitalWrite(LED_PIN, HIGH);
  }
  else if ( 90.0 <= spd && spd < 180.0){
    pos =  1531;
    digitalWrite(LED_PIN, HIGH);
  }
  else if ( 45.0 <= spd && spd < 90.0)
  {
    pos =  1520;
    digitalWrite(LED_PIN, HIGH);
  }
  else if ( 22.0 < spd && spd < 45.0)
  {
    pos =  1515;
    digitalWrite(LED_PIN, HIGH);
  }
  else if ( -22.0 <= spd && spd <= 22.0) {
    pos =  SERVO_CENTER;
    digitalWrite(LED_PIN, LOW);
  }
  else if ( -45.0 < spd && spd < -22.0)
  {
    pos =  1485;
    digitalWrite(LED_PIN, HIGH);
  }
  else if ( -90.0 < spd && spd <= -45.0)
  {
    pos =  1479;
    digitalWrite(LED_PIN, HIGH);
  }
  else if ( -180.0 < spd && spd <= -90.0){
    pos =  1469;
    digitalWrite(LED_PIN, HIGH);
  }
  else if ( -300.0 < spd && spd <= -180.0){
    pos =  1436;
    digitalWrite(LED_PIN, HIGH);
  }
  else if (spd <= -300.0 ) { 
    pos = 1300;
    digitalWrite(LED_PIN, LOW);
  }

  servo1.writeMicroseconds(pos);              // Actully setting the speed.
  rpos = map(pos, 1300, 1700, 1700, 1300); // Reverse the direction for the other side
  servo2.writeMicroseconds(rpos);
  return abs(pos - SERVO_CENTER); //  return the pulse width value as an offset from center.
}


/*
---------------------- Composite Filter -------------------------------------------
 */

void Cfilterbegin(){
  //Turning on the accelerometer
  Accel.init(ADXL345_ADDR_ALT_LOW);
  Accel.set_bw(ADXL345_BW_12);

  gyro.reset();
  // Use ITG3200_ADDR_AD0_HIGH or ITG3200_ADDR_AD0_LOW as the ITG3200 address 
  // depending on how AD0 is connected on your breakout board, check its schematics for details
  gyro.init(ITG3200_ADDR_AD0_LOW);  
  DEBUG_PRINT("zeroCalibrating...");
  gyro.zeroCalibrate(2500,2);
  DEBUG_PRINTLN("done.");

  alpha = TIME_CONSTANT / (TIME_CONSTANT + SAMPLE_RATE); // calculate the scaling coefficent
  DEBUG_PRINT("Scaling Coefficent: ");
  DEBUG_PRINTLN(alpha); 

  delay(100); 
}

// ------------------ Convienence Function -------------------------

float absMax(float a, float b){ // returns the value that is further from center (zero)
  if (abs(a) > abs(b)){
    return a;
  }
  else {
    return b;
  }
}

// ------------------ read Accelerometer angles ---------------------

void getAccAngle() { //compute The actual theta and psi values from the Accelerometer readings

  float acc_data[3];
  Accel.get_Gxyz(acc_data);
  /* The correct calculation
   theta = atan(acc_data[0]/sqrt(acc_data[1]*acc_data[1] + acc_data[2]*acc_data[2]))*180/PI; 
   psi = atan(acc_data[1]/sqrt(acc_data[0]*acc_data[0] + acc_data[2]*acc_data[2]))*180/PI;
   phi=  atan(sqrt(acc_data[0]*acc_data[0] + acc_data[1]*acc_data[1])/acc_data[2])*180/PI; // Not needed since we only care bout x and y
   */
  theta = (acc_data[0]/sqrt(acc_data[1]*acc_data[1] + acc_data[2]*acc_data[2]))*180/PI; //drop atan for computation speed, small angle aproximation
  psi = (acc_data[1]/sqrt(acc_data[0]*acc_data[0] + acc_data[2]*acc_data[2]))*180/PI;
}

// ------------------ read gyroscope angles ---------------------

void getGyroValues(){ // Simple reading of gyro values
  float xyz[3];
  gyro.readGyro(xyz);
  gx = xyz[0];
  gy = xyz[1];
  gz = xyz[2];
}

//------------------ Composite Filter ----------------

float compositeFilter(float acc, float gyro, float rate, float angle){
  return alpha * (angle + (gyro * rate))  + (1 - alpha) * acc; // the actual filter
}

/*
-------------------------- Aurdino Code -------------------------------
 */

void setup()
{
  pinMode(LED_PIN, OUTPUT);
  digitalWrite(LED_PIN, HIGH);
  DEBUG_BEGIN(115200);
  Wire.begin();         

  Cfilterbegin();
  DEBUG_PRINT("Computing Refrence angle...:"); 
  for (int i = 0; i < REF_ANGLE_SAMPLES; i++){
    getAccAngle();
    getGyroValues();
    maxGyro = absMax(gy,absMax(gx,gz)); 
    maxAngle = absMax(theta,psi);

    angle = compositeFilter( maxAngle, float(maxGyro), SAMPLE_RATE, angle); //angle tilt and move the clock up
    DEBUG_PRINTLN("Ref angle calc: ");
    DEBUG_PRINTLN(angle);
    refAngle += angle; // Add up the samples
    delay(SAMPLE_RATE);
  }
  refAngle /= REF_ANGLE_SAMPLES; // Divide by the number of samples to get the average
  angle = 0; // Reset the Filter

  DEBUG_PRINTLN(refAngle);
  digitalWrite(LED_PIN, LOW);
  lastMilli = millis();
  SBRServoBegin(SERVO1_PIN, SERVO2_PIN, lastMilli);
}

void loop() 
{
  curMilli = millis();

  if ((curMilli - lastMilli) > SAMPLE_RATE){
    getAccAngle(); // Read the devices
    getGyroValues();

    rate = (float(curMilli) - float(lastMilli)) / 1000.0; // Calculate the actual rate in seconds (Gryo read outs are in seconds).

    maxGyro = absMax(gy,absMax(gx,gz)); //Since we can react to only one direction, it is assume to be maximal
    maxAngle = absMax(theta,psi);

    angle = compositeFilter( maxAngle, float(maxGyro), rate, angle); //angle tilt and move the clock up
    lastMilli = curMilli;  

    float error =  angle - refAngle;

    if (-3 < error && error < 3){ // error thresholding
      error = 0;
    }

    integral = constrain(integral + error * rate, -INTEGRAL_LIMIT, INTEGRAL_LIMIT); // constrain the integral so we don't have to relax from really far values 
    derivative = (error - prevError) / rate;
    spd = (KP * error) + (KI * integral) + (KD * derivative); // Compute the speed to set the acceleromter
    resPos = setSPD(spd, curMilli); //set the Speed 
    prevError = error;    

    // Debug Output
    if (resPos  != -1){ // Only print when we change something
      DEBUG_PRINT(curMilli);
      DEBUG_PRINT(" , ");
      DEBUG_PRINT(maxAngle);
      DEBUG_PRINT(" , ");
      DEBUG_PRINT(maxGyro);
      DEBUG_PRINT(" , ");
      DEBUG_PRINT(angle); // remove the refrence from the display
      DEBUG_PRINT(" , ");
      DEBUG_PRINT(maxAngle - angle); // remove the refrence from the display
      DEBUG_PRINT(" , ");
      DEBUG_PRINT(error);
      DEBUG_PRINT(" , ");
      DEBUG_PRINT(rate);
      DEBUG_PRINT(" , ");
      DEBUG_PRINT(error * rate );
      DEBUG_PRINT(" , ");
      DEBUG_PRINT(integral);
      DEBUG_PRINT(" , ");
      DEBUG_PRINT(derivative);
      DEBUG_PRINT(" , ");
      DEBUG_PRINT(spd);
      DEBUG_PRINT(" , ");
      DEBUG_PRINTLN(resPos); 
    }
    else{
      DEBUG_PRINTLN("Skipping"); 
    }
  }
  else if((curMilli - lastMilli) < 0){ // time variable wraped around 
    lastMilli = curMilli;
  }
}

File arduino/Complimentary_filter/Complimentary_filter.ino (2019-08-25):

/*
 *
 * Compute the composite filter angle and gyro rates.
 * theta, psi, phi and gx,gy,gz
 *
 */
#include <Wire.h>
#include <Arduino.h>
#include <ADXL345.h>
#include <math.h>
#include <ITG3200.h>
#include <Cfilter.h>

unsigned long curMicro = 0, lastMicro = 0, prevMicro = 0, rate = 0;

float angle = 0;


//------------- Begin Aurdino doing stuff ---------------
void setup()
{
  Serial.begin(115200); // Fastest Transfer rate?
  Wire.begin();         
 
  Cfilterbegin();
  
  lastMicro = micros();
  prevMicro = lastMicro;
}



void loop()
{
  curMicro = micros();
  getAccAngle(); // Internal updates
  getGyroValues(); 

  if ((curMicro - lastMicro) > SAMPLE_RATE){
    rate = (curMicro - prevMicro) / 100000; // Calculate the actual rate in seconds (Gryo read outs are in seconds).
    angle = compositeFilter( max(theta,psi),max(gy,max(gx,gz)), rate, angle); //compute the worst angle tilt
    lastMicro = curMicro;
    Serial.print(curMicro);
    Serial.print(" , ");
    Serial.print(angle);
    Serial.print(" , ");
    Serial.println(max(gy,max(gx,gz)));

  }
  else if((curMicro - lastMicro) < 0){
    lastMicro = curMicro;
  }
  prevMicro = curMicro;
}

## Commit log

2013-06-03 Initial laser cut body. OOps, no cut outs for servos.
2013-06-03 Added servo mounts with holes.
2013-06-03 The holes weren't lines.
2013-06-04 Added taller bot with precise servo cut out.
2013-06-04 Added FubarStep mounting holes.
2013-06-05 Need to use the better holes.
2013-06-05 Fixing the servo lines again.
2013-06-07 added some documentation and diagnostic data.
    [JustAccellAngle.xlsx]
2013-06-24 Merged in the code from James.
    [ServoCalibratordegree.ino]
2013-06-24 Added the readme for the servo calibration.
2013-06-29 Cleaned up conflicts
    [CombFilCal.xlsx]
2013-06-30 Images of the redesiged board, and some code mods for said board
2013-07-01 Made complimentary filter a lib
2013-07-02 added an absMax method to fiter code to resolve direction problem, and fixed the servo lib to set spd to max for out of range request. Computed ref angle in robot code, and set LED Hi and low when ca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
2013-07-05 Fixed direction on the servo, and removed the pot from the Robot code
    [ServoCalibratordegree.ino]
2013-07-06 Servo Calibration Curve
    [ServoCalibaration.xlsx]
2013-07-08 Notes update, generating slides
    [ServoCalibaration.xlsx]
2013-07-08 Slides for Accelerometer discussion
2013-07-08 Sample data, and completed Acc Slides (needs Gyro and Servo)
    [ExampleAccData.xlsx]
2013-07-10 A pid implmentation with porper servo calibration and a gain factor
    [ServoExact.xlsx]
2013-07-11 More robot code tweaks and clean up, and gyro - filter slides + example
2013-07-12 Servo Slides
2013-07-12 PID works with out robot, but fails when robot is attached?
    [RobotSinglePID.ino]
2013-07-14 Fixed the setup to use compfilter to generate ref angle, and corrected some type conversion problems with spd. Set spd expects a float now
    [RobotSinglePID.ino]
2013-07-15 Update the orientation of servos and platform.
2013-07-15 PID example
2013-07-16 Robot Circuit drawings and Frizt
    [robut.fzz]
